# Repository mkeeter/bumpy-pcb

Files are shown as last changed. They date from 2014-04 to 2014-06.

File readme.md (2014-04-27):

## About

This repository contains hardware for the [bumpy](http://mattkeeter.com/projects/bumpy)
mp3 player.

## License

Copyright (c) 2014 Matthew Keeter

Permission is hereby granted, free of charge, to any person obtaining a copy of this hardware, software, and associated documentation files (the "Product"), to deal in the Product without restriction, including without limitation the rights to use, copy, modify, merge, publish, distribute, sublicense, and/or sell copies of the Product, and to permit persons to whom the Product is furnished to do so, subject to the following conditions:

The above copyright notice and this permission notice shall be included in all copies or substantial portions of the Product.

THE PRODUCT IS PROVIDED "AS IS", WITHOUT WARRANTY OF ANY KIND, EXPRESS OR IMPLIED, INCLUDING BUT NOT LIMITED TO THE WARRANTIES OF MERCHANTABILITY, FITNESS FOR A PARTICULAR PURPOSE AND NONINFRINGEMENT. IN NO EVENT SHALL THE AUTHORS OR COPYRIGHT HOLDERS BE LIABLE FOR ANY CLAIM, DAMAGES OR OTHER LIABILITY, WHETHER IN AN ACTION OF CONTRACT, TORT OR OTHERWISE, ARISING FROM, OUT OF OR IN CONNECTION WITH THE PRODUCT OR THE USE OR OTHER DEALINGS IN THE PRODUCT.

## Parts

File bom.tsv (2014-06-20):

Name | Vendor | Part number | Count | Identifier
12.288 MHz crystal | Digikey | XC1771CT-ND | 1 | Y2
8 MHz crystal | Digikey | XC1271CT-ND | 1 | Y1
Power switcher | Digikey | 296-34595-5-ND | 1 | U1
Encoder wheel | Digikey | P13381SCT-ND | 1 | S2
8-bit shift register | Digikey | 568-2263-1-ND | 1 | U6
Green LED (1206) | Digikey | 160-1169-1-ND | 8 | LED1-8
2.8V buck regulator | Digikey | LM3671MF-2.8/NOPBCT-ND | 1 | U5
3.3V buck regulator | Digikey | LM3671MF-3.3/NOPBCT-ND | 1 | U4
2.2uH inductor | Digikey | 541-1236-1-ND | 2 | L1, L2
Slide switch | Digikey | 401-1999-1-ND | 1 | S1
MicroSD holder | Digikey | 732-3819-1-ND | 1 | U3
USB mini plug | Digikey | ED2992CT-ND | 1 | JP1
Audio jack | Digikey | CP-3523SJCT-ND | 1 | U7
6-pin FTDI header | Digikey | A106757-ND | 1 | JP2
6-pin SPI header | Digikey | A106478-ND | 1 | J1
Atmega32u4 | Digikey | ATMEGA32U4-AURCT-ND | 1 | U9
Max1555 charger | Digikey | MAX1555EZK+TCT-ND | 1 | U2
10 Ohm 0603 resistor | Digikey | P10GCT-ND | 3 | R17, R18, R19
22 Ohm 0603 resistor | Digikey | P22GCT-ND | 2 | R1, R2
75 Ohm 0603 resistor | Digikey | P75GCT-ND | 8 | R24-31
100 Ohm 0603 resistor | Digikey | P100GCT-ND | 2 | R20, R21
392 Ohm 0603 resistor | Digikey | P392HCT-ND | 1 | R5
10 Kohm 0603 resistor | Digikey | P10KGCT-ND | 7 | R3, R4, R10, R11, R22, R23
100 Kohm 0603 resistor | Digikey | P100KGCT-ND | 5 | R7, R12,R13, R14, R16
1 MOhm 0603 resistor | Digikey | P1.0MGCT-ND | 1 | R15
33 pF 0603 capacitor | Digikey | 1276-2267-1-ND | 4 | C5, C6, C11, C12
10 nF 0603 capacitor | Digikey | 445-1311-1-ND | 2 | C28, C29
47 nF 0603 capacitor | Digikey | 445-1313-1-ND | 1 | C27
0.1 uF 0603 capacitor | Digikey | 445-1314-1-ND | 12 | C2, C3, C8, C15, C16, C17, C19, C20, C21, C22, C23, C24, C25
1 uF 0603 capacitor | Digikey | 445-1322-1-ND | 4 | C4, C7, C18, C26
4.7 uF 0603 capacitor | Digikey | 445-5178-1-ND | 2 | C9, C10
10 uF 0603 capacitor | Digikey | 445-4112-1-ND | 5 | C1, C13, C14, C30, C31
1000 mAh Lithium battery | Sparkfun | PRT-00339 | 1 | JP3
MP3 codec | Sparkfun | COM-09398 | 1 | U8

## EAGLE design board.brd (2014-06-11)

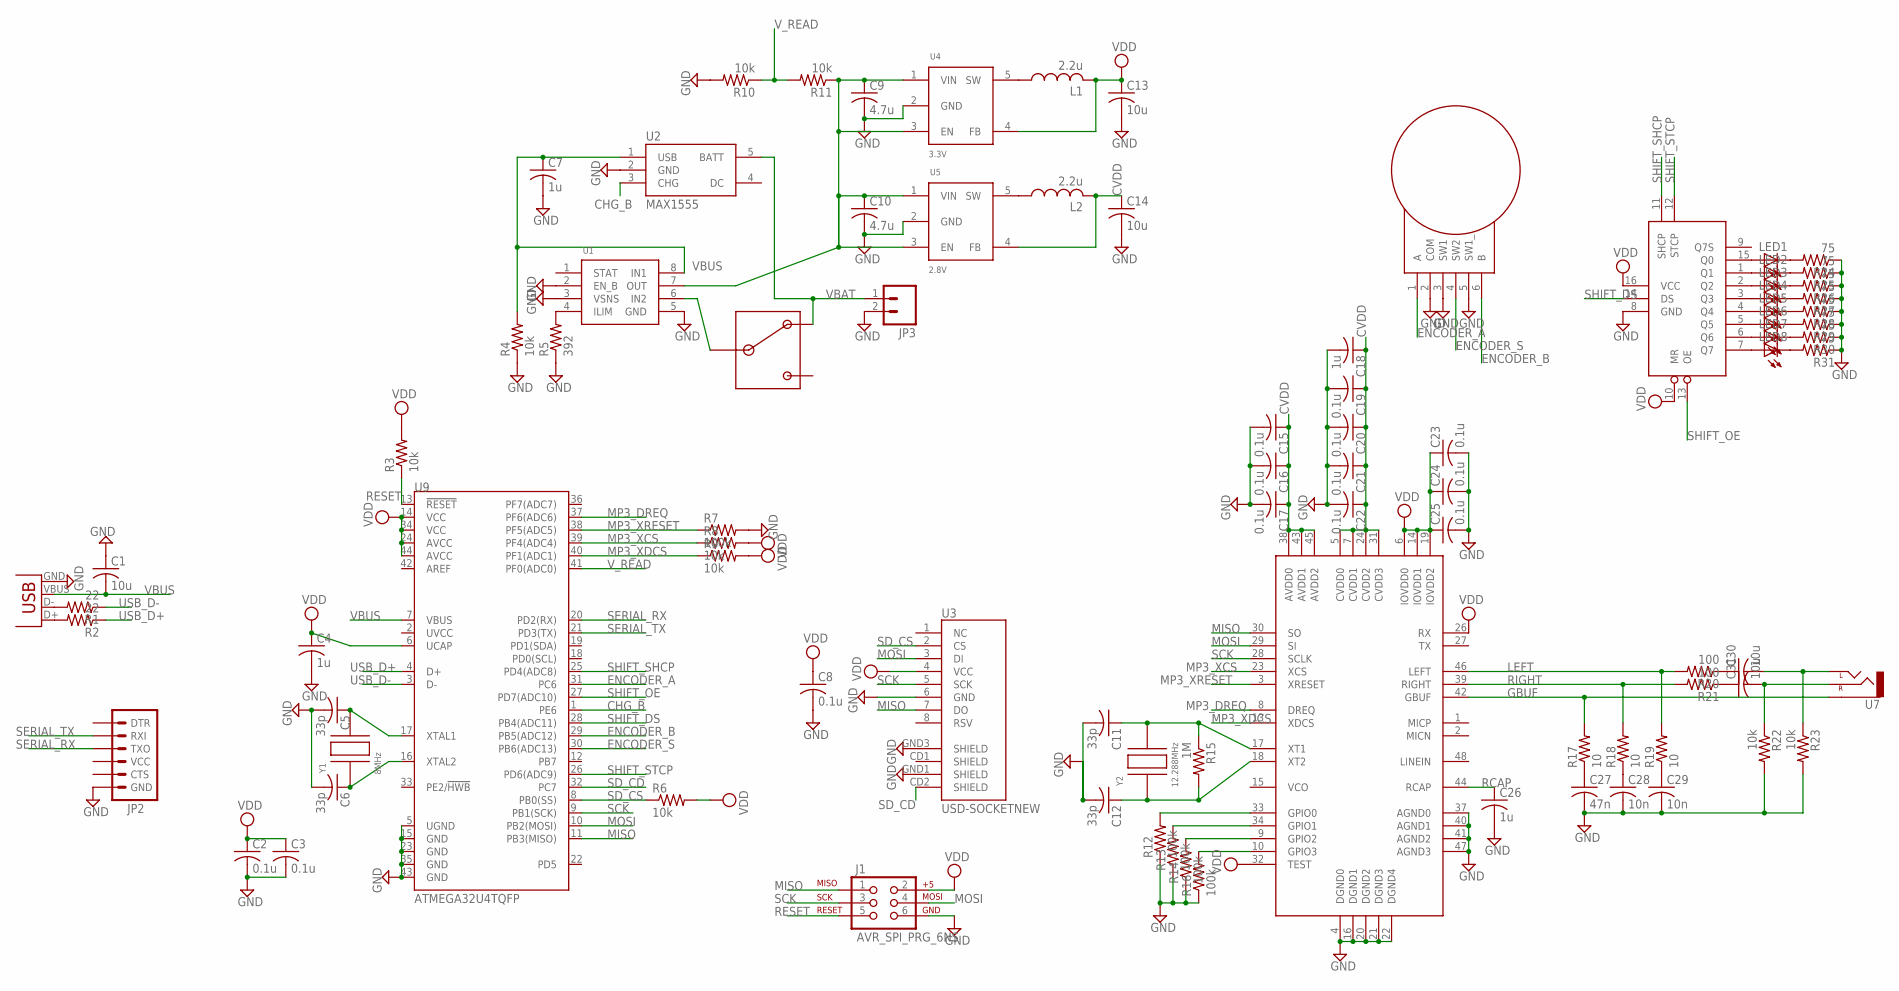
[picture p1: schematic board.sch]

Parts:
C1, C13, C14, C30, C31: 10u; C0603K
C2, C3, C8, C15, C16, C17, C19, C20, C21, C22, C23, C24, C25: 0.1u; C0603K
C4, C7, C18, C26: 1u; C0603K
C5, C6, C11, C12: 33p; C0603K
C9, C10: 4.7u; C0603K
C27: 47n; C0603K
C28, C29: 10n; C0603K
J1: AVR_SPI_PRG_6NS; 2X3-NS
JP1: USBSMD; USB-MINIB
JP2: ARDUINO_SERIAL_PROGRAMLOCK; 1X06_LOCK
JP3: M02PTH; 1X02
L1, L2: 2.2u; IHLP-2020CZ-11
LED1, LED2, LED3, LED4, LED5, LED6, LED7, LED8: LED1206; LED-1206
R1, R2: 22; R0603W
R3, R4, R10, R11: 10k; R0603
R5: 392; R0603
R6, R8, R9, R22, R23: 10k; R0603W
R7, R12, R13, R14, R16: 100k; R0603W
R15: 1M; R0603
R17, R18, R19: 10; R0603W
R20, R21: 100; R0603W
R24, R25, R26, R27, R28, R29, R30, R31: 75; R0603W
S1: JS102011SAQN
S2: EVQ-WKA
U1: TPS2112A; TSSOP8
U2: MAX1555; SOT23-5
U3: USD-SOCKETNEW; MICRO-SD-SOCKET-PP
U4: 3.3V; SOT23-5
U5: 2.8V; SOT23-5
U6: 74HC595; TSSOP16
U7: AUDIO-JACKSMD2; AUDIO-JACK-3.5MM-SMD
U8: VS1003; LQFP-48
U9: ATMEGA32U4TQFP; SPARKFUN-DIGITALIC_TQFP44
Y1: 8MHz; HC49/US
Y2: 12.288MHz; CSM-3X

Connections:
CHG_B: U2.3 (CHG), U9.1 (PE6)
CVDD: C14.1, C15.1, C16.1, C17.1, C18.1, C19.1, C20.1, C21.1, C22.1, L2.P$2 (2), U5.4 (FB), U8.5 (CVDD0), U8.7 (CVDD1), U8.24 (CVDD2), U8.31 (CVDD3), U8.38 (AVDD0), U8.43 (AVDD1), U8.45 (AVDD2)
ENCODER_A: S2.1 (A), U9.31 (PC6)
ENCODER_B: S2.6 (B), U9.29 (PB5(ADC12))
ENCODER_S: S2.4 (SW2), U9.30 (PB6(ADC13))
GBUF: R17.2, U7.SLEEVE, U8.42 (GBUF)
GND: C1.1, C2.2, C3.2, C4.2, C5.2, C6.2, C7.2, C8.2, C9.2, C10.2, C11.2, C12.2, C13.2, C14.2, C15.2, C16.2, C17.2, C18.2, C19.2, C20.2, C21.2, C22.2, C23.2, C24.2, C25.2, C26.2, C27.2, C28.2, C29.2, J1.6, JP1.GND, JP2.6 (GND), JP3.2, R4.1, R5.1, R7.2, R10.2, R12.1, R13.1, R14.1, R16.1, R22.2, R23.2, R24.1, R25.1, R26.1, R27.1, R28.1, R29.1, R30.1, R31.1, S2.2 (COM), S2.3 (SW1), S2.5 (SW1_), U1.2 (EN_B), U1.3 (VSNS), U1.5 (GND), U2.2 (GND), U3.6 (GND), U3.GND1 (SHIELD), U3.GND3 (SHIELD), U4.2 (GND), U5.2 (GND), U6.8 (GND), U8.4 (DGND0), U8.16 (DGND1), U8.20 (DGND2), U8.21 (DGND3), U8.22 (DGND4), U8.37 (AGND0), U8.40 (AGND1), U8.41 (AGND2), U8.47 (AGND3), U9.5 (UGND), U9.15 (GND), U9.23 (GND), U9.35 (GND), U9.43 (GND)
GPIO0: R12.2, U8.33 (GPIO0)
GPIO1: R13.2, U8.34 (GPIO1)
GPIO2: R14.2, U8.9 (GPIO2)
GPIO3: R16.2, U8.10 (GPIO3)
LEFT: R19.2, R20.2, U8.46 (LEFT)
MISO: J1.1, U3.7 (DO), U8.30 (SO), U9.11 (PB3(MISO))
MOSI: J1.4, U3.3 (DI), U8.29 (SI), U9.10 (PB2(MOSI))
MP3_DREQ: U8.8 (DREQ), U9.37 (PF6(ADC6))
MP3_XCS: R8.1, U8.23 (XCS), U9.39 (PF4(ADC4))
MP3_XDCS: R9.1, U8.13 (XDCS), U9.40 (PF1(ADC1))
MP3_XRESET: R7.1, U8.3 (XRESET), U9.38 (PF5(ADC5))
unnamed: JP1.D-, R1.2
unnamed: C5.1, U9.17 (XTAL1), Y1.P$2
unnamed: C27.1, R17.1
unnamed: C28.1, R18.1
unnamed: C29.1, R19.1
unnamed: JP1.D+, R2.2
unnamed: C12.1, R15.2, U8.18 (XT2), Y2.P$1
unnamed: C11.1, R15.1, U8.17 (XT1), Y2.P$2
unnamed: C31.1, R21.1
unnamed: C30.1, R20.1
unnamed: C31.2, R22.1, U7.RING (RIGHT)
unnamed: C30.2, R23.1, U7.TIP (LEFT)
unnamed: C6.1, U9.16 (XTAL2), Y1.P$1
unnamed: R5.2, U1.4 (ILIM)
unnamed: C9.1, C10.1, R11.1, U1.7 (OUT), U4.1 (VIN), U4.3 (EN), U5.1 (VIN), U5.3 (EN)
unnamed: LED8.A, U6.7 (Q7)
unnamed: LED7.A, U6.6 (Q6)
unnamed: LED6.A, U6.5 (Q5)
unnamed: LED5.A, U6.4 (Q4)
unnamed: LED4.A, U6.3 (Q3)
unnamed: LED3.A, U6.2 (Q2)
unnamed: LED2.A, U6.1 (Q1)
unnamed: LED1.A, U6.15 (Q0)
unnamed: LED1.C, R24.2
unnamed: LED2.C, R25.2
unnamed: LED3.C, R26.2
unnamed: LED4.C, R27.2
unnamed: LED5.C, R28.2
unnamed: LED6.C, R29.2
unnamed: LED7.C, R30.2
unnamed: LED8.C, R31.2
unnamed: L1.P$1 (1), U4.5 (SW)
unnamed: L2.P$1 (1), U5.5 (SW)
unnamed: S1.P$2 (2), U1.6 (IN2)
RCAP: C26.1, U8.44 (RCAP)
RESET: J1.5, R3.1, U9.13 (!RESET)
RIGHT: R18.2, R21.2, U8.39 (RIGHT)
SCK: J1.3, U3.5 (SCK), U8.28 (SCLK), U9.9 (PB1(SCK))
SD_CD: U3.CD2 (SHIELD), U9.32 (PC7)
SD_CS: R6.1, U3.2 (CS), U9.8 (PB0(SS))
SERIAL_RX: JP2.3 (TXO), U9.20 (PD2(RX))
SERIAL_TX: JP2.2 (RXI), U9.21 (PD3(TX))
SHIFT_DS: U6.14 (DS), U9.28 (PB4(ADC11))
SHIFT_OE: U6.13 (OE), U9.27 (PD7(ADC10))
SHIFT_SHCP: U6.11 (SHCP), U9.25 (PD4(ADC8))
SHIFT_STCP: U6.12 (STCP), U9.26 (PD6(ADC9))
USB_D+: R2.1, U9.4 (D+)
USB_D-: R1.1, U9.3 (D-)
VBAT: JP3.1, S1.P$3 (3), U2.5 (BATT)
VBUS: C1.2, C7.1, JP1.VBUS, R4.2, U1.8 (IN1), U2.1 (USB), U9.7 (VBUS)
VDD: C2.1, C3.1, C4.1, C8.1, C13.1, C23.1, C24.1, C25.1, J1.2, L1.P$2 (2), R3.2, R6.2, R8.2, R9.2, U3.4 (VCC), U4.4 (FB), U6.10 (MR), U6.16 (VCC), U8.6 (IOVDD0), U8.14 (IOVDD1), U8.19 (IOVDD2), U8.26 (RX), U8.32 (TEST), U9.6 (UCAP), U9.14 (VCC), U9.24 (AVCC), U9.34 (VCC), U9.44 (AVCC)
V_READ: R10.1, R11.2, U9.41 (PF0(ADC0))

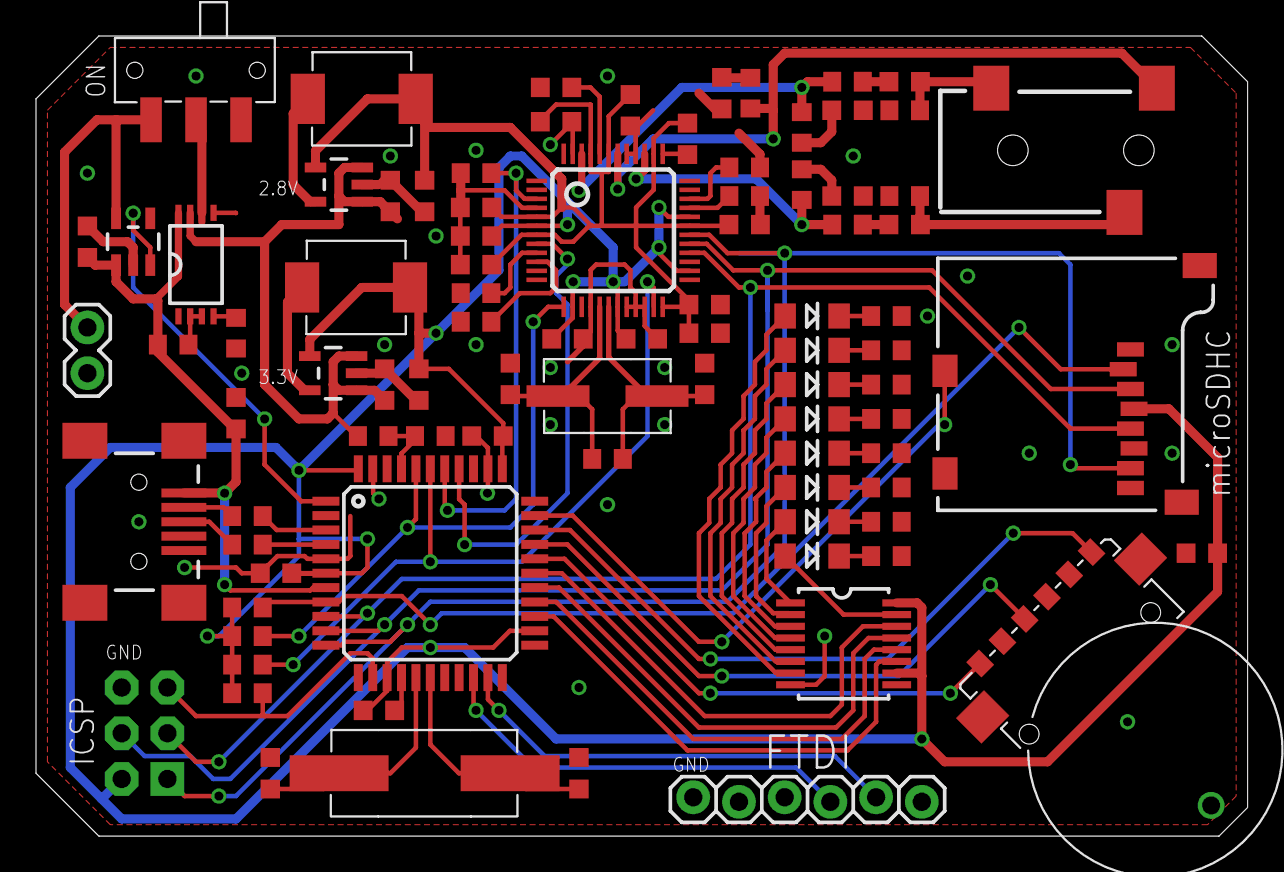
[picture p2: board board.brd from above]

Board: 2 copper layers, 67.3 x 44.4 mm, 89 parts (0 on the bottom side), 70 nets.

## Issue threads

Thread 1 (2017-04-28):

Encoder discontinued / EOL

towerofbabel, 2017-04-28:
I'm not sure if the author (or anyone) is willing to continue working on this project but when evaluating it to learn and perhaps build it, I noticed that the encoder is now discontinued.

P13381SCT-ND

Panasonic stopped making this in 2015 and there doesn't seem to be any compatible parts on the market. This means that the board needs re-designed.

mkeeter, I'm not strong on PCB layouts. If you have any advice on free software or what approach might be good to take, please let me know, if you still care about the bumpy project.

I think bumpy is important because one day, we won't have any mp3 players to run Rockbox on. Hey, maybe we can get a small LCD screen on bumpy someday and run Rockbox? I think the SoC is a bit out of date as well. A better chip that also supports .ogg would be nice.

I'm really new to the maker community. In my spare time, I plan on continuing to develop this project. I have a lot to learn though so if anyone else would mind jumping in for leadership or advice, I would really appreciate it, because it's going to take me some time (on the order of one year) before I can make meaningful contributions.

Let's not let this project die.

towerofbabel, 2017-04-28:
Let me also say that Mr. Keeter, you've done a fine job on this project and I'm really happy that you gave this to the community. Cheers!

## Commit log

2013-12-05 Here comes the files
    [board.brd, board.sch]
2013-12-05 Connected XTest on vs1063 to VDD
    [board.brd, board.sch]
2013-12-05 Added pull-ups to mp3 cs lines
    [board.brd, board.sch]
2013-12-05 Beginning to switch to atmega32u2
    [board.brd, board.sch]
2013-12-05 Switched to smaller uC and VS1003 chip
    [board.brd, board.sch]
2013-12-05 Finished layout
    [board.brd, board.sch]
2013-12-05 Not sure why I shorted VDD with an open-drain output to ground.
    [board.brd, board.sch]
2013-12-05 Switched to 0603W packages for audio path resistors
    [board.brd, board.sch]
2013-12-05 Shifted VS1003 over a bit
    [board.brd]
2013-12-05 Moved shift register over a bit
    [board.brd]
2013-12-05 Board shrink
    [board.brd]
2013-12-05 Renumbered parts
    [board.brd, board.sch]
2013-12-05 PCB trace cleaning
    [board.brd]
2013-12-05 Fixed scroll wheel package (lousy datasheet!)
    [board.brd, board.sch]
2013-12-05 0.1" shrink on y axis
    [board.brd]
2013-12-05 Moved SPI header to fit battery
    [board.brd]
2013-12-05 Moved battery plug and SD capacitor
    [board.brd]
2013-12-05 Switched audio plug to 3-pin version and added OE connection
    [board.brd, board.sch]
2013-12-05 Fixed rear silkscreen
    [board.brd, board.sch]
2013-12-05 Capacitor value fixes and obsessive pcb trace cleanup
    [board.brd, board.sch]
2013-12-05 More board cleanup
    [board.brd, board.sch]
2013-12-05 Removed battery outline
    [board.brd]
2013-12-05 Misaligned top layer
    [board.brd]
2013-12-05 Tightened resistor spacing
    [board.brd, board.sch]
2013-12-05 Moved voltage labels
    [board.brd]
2013-12-05 Debugging rev2 board
    [board.brd, board.sch]
2013-12-05 Switching back to atmega32u4
    [board.brd, board.sch]
2013-12-05 Rough connections are made.
    [board.brd, board.sch]
2013-12-05 More connections
    [board.brd, board.sch]
2013-12-07 A bit more beveling on corners
    [board.brd]
2013-12-07 Ignore temporary board and schematic files
2013-12-07 Make wheel stick out more
    [board.brd]
2013-12-07 Added battery sense, updated revision, and centered LEDs
    [board.brd, board.sch]
2013-12-07 Trace cleanup
    [board.brd]
2013-12-07 A bit more space between audio jack and sdhc
    [board.brd]
2013-12-08 Move switch to be flush with board
    [board.brd, board.sch]
2013-12-08 More trace cleanup
    [board.brd]
2013-12-08 Removed battery cutout on milling layer
    [board.brd]
2013-12-09 More trace cleaning
    [board.brd]
2013-12-09 Last bit of cleanup
    [board.brd]
2013-12-09 Moved revision number to bottom
    [board.brd]
2013-12-09 More gap between LEDs and shift register
    [board.brd]
2014-03-18 Why wasn't UCAP connected to VDD?
    [board.brd, board.sch]
2014-04-24 Adding bom
    [bom.tsv]
2014-04-27 Atmega32u2 -> u4
    [bom.tsv]
2014-06-06 Bump revision
    [board.brd]
2014-06-06 ...and bump release date
    [board.brd]
2014-06-11 Re-ordered components, added identifiers to BOM, and fixed power switching
    [board.brd, board.sch, bom.tsv]
2014-06-11 Bump version number
    [board.brd]
2014-06-11 Adding assembly diagram
2014-06-11 Fix weird unicode that snuck into the BOM
    [bom.tsv]
2014-06-20 Added missing resistors to bom
    [bom.tsv]

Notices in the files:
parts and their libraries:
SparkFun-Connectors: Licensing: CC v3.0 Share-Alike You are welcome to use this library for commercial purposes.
